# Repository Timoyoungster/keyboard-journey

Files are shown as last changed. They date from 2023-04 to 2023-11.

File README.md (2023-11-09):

# keyboard-journey
*(This repo is for my future self)*
- some crappy plastic full sized keyboard (membrane)
- a sharkoon full sized keyboard (membrane)
- a corsair K70 (mechanical) *not sure about the exact model*
- a razer blackwidow chroma (mechanical; green switches)
- a razer blackwidow chroma (mechanical; orange switches)
- a razer deathstalker pro v2 (mechanical; *i think orange switches*)
- a ferris sweep half-swept (mechanical; Kailh Low Profile Choc Switches Pink (linear / 20gf))

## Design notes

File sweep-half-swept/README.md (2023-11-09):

# Sweep Half Swept

| Front | Back |
| --- | --- |
|  |  |

Half of a Sweep2 with a reversible micro-controller footprint.

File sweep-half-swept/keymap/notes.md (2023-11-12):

# VERY IMPORTANT!!!!
even though it has a TRS/TRRS jack, a TRRS cable is necessary for it to function

If it still doesn't work add the following to the config:
```c
#define SPLIT_USB_DETECT
#define SPLIT_USB_TIMEOUT 2500
```
or try:
```c
#define SPLIT_USB_DETECT
#define SPLIT_USB_TIMEOUT_POLL 10
#define SPLIT_WATCHDOG_ENABLE
#define SPLIT_WATCHDOG_TIMEOUT 3000
```

# KEYMAP SETUP

Make sure to use the LAYOUT_split_3x5 macro for defining the layers (not LAYOUT)

## RULES
SPLIT_KEYBOARD = yes *(to make split mode work)*
COMBO_ENABLE = yes *(to enable the combo feature)*
CONVERT_TO = elite_pi *(to compile for the elite pi controller)*

## CONFIG.H
don't forget to add "#define EE_HANDS" to set the handedness on the EEPROM

# COMPILE & FLASH FIRMWARE
*(board needs to be connected and in boot mode for this
as the command flashes the firmware directly after compilation)*

For the *left side*:
```
qmk flash -bl uf2-split-left
```
For the *right side*:
```
qmk flash -bl uf2-split-right
```

# ELITE-PI - BOOT MODE
In order to get the elite-pi into boot mode it has to be unplugged.

Then the "BOOT" pad and the 4th pin from the top on the right have to be connected with a wire / paperclip or a similar item.

With those two connectors bridged, the USB-C cable has to be plugged in and can only be released when windows recognises the USB-device (when it shows up as a drive in the explorer).

# PROBLEMS
- some weird bug that makes the mouse click unusable when escaping from arrow layer after having selected with shift and arrow keys or something like that; effect is that all mouse clicks deregister right after registering -> nothing can be clicked anymore

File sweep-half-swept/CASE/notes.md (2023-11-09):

# Notes
## Failed Ideas
- screwing a plate onto the bottom piece to hold the PCB from the top doesn’t work because the Elite-PI is on the edge
- using cylindrical extrusions to fit the top to the bottom doesn’t work because the cylinders break easily when a bit of rotational force is applied
- using velcro to attach the PCB to the bottom piece doesn’t work as it makes the PCB feel mushy and if the Elite-PI’s side is pressed down it could damage the cables/ports

## WIP Ideas
### attaching the top to the bottom piece
- DONE: embedding magnets into the top and bottom pieces to keep the surfaces clean and still hold them together tightly (maybe using longer rectangular-shaped ones would be better than circular ones)

### fixating the PCB to the bottom piece
- drill one mounting hole somewhere as far into the middle as possible (inside of the triangle the standoffs form) and use brass insets to fixate the PCB to the case

### making space for the cables
- if possible let the PCB sit higher than the bottom piece’s wall so that there is enough room for the USB-C and AUX cable
- DONE: make a big enough cylindrical "dent"/cutout for the aux port and a similar one in a USB-C shape

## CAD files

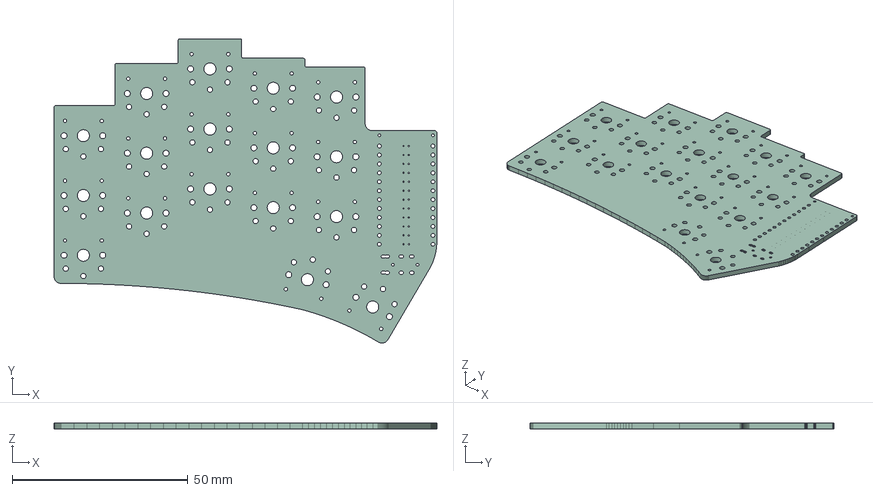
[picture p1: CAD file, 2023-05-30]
sweep-half-swept/half-swept.step
108.9 x 86.5 x 1.58 mm

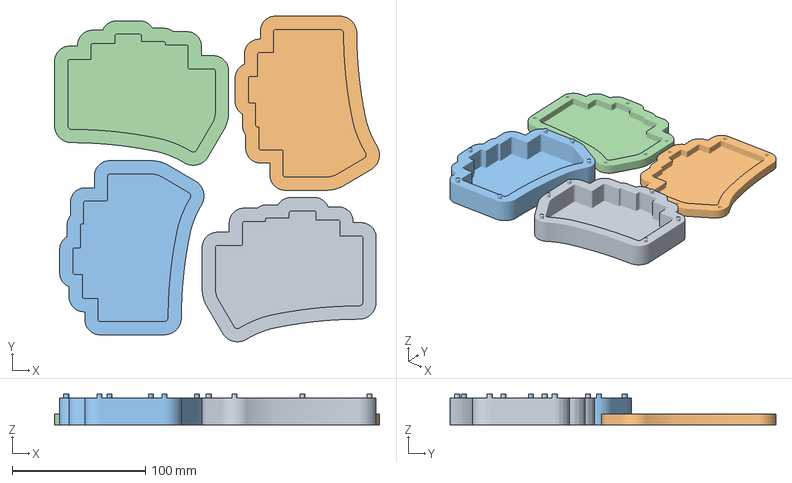
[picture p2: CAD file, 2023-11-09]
sweep-half-swept/CASE/ferris-sweep-case V2.1.3mf
244.3 x 244.8 x 23.0 mm
CASE_top_right
CASE_bottom_right_
CASE_top_left
CASE_bottom_left

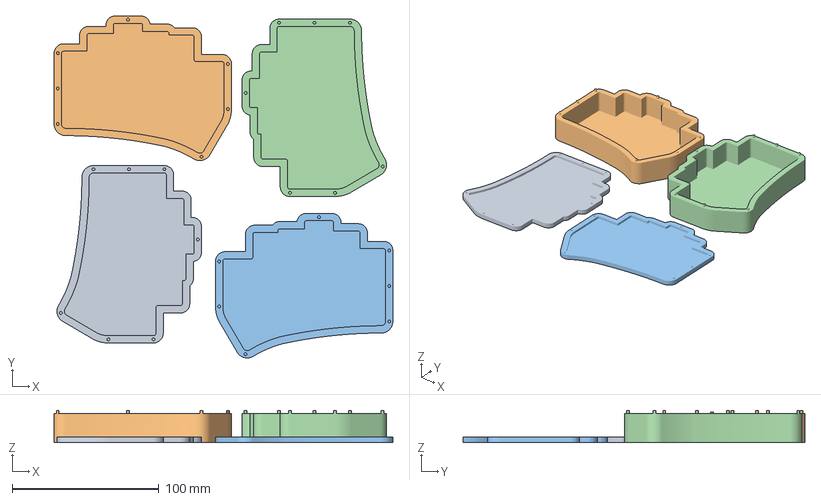
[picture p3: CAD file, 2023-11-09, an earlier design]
sweep-half-swept/CASE/ferris-sweep-case V2.0.3mf
230.9 x 233.0 x 22.0 mm
CASE_Bottom_left
CASE_Bottom_left_(1)
CASE_Bottom_left_(1)_(2)
CASE_Bottom_left_(2)

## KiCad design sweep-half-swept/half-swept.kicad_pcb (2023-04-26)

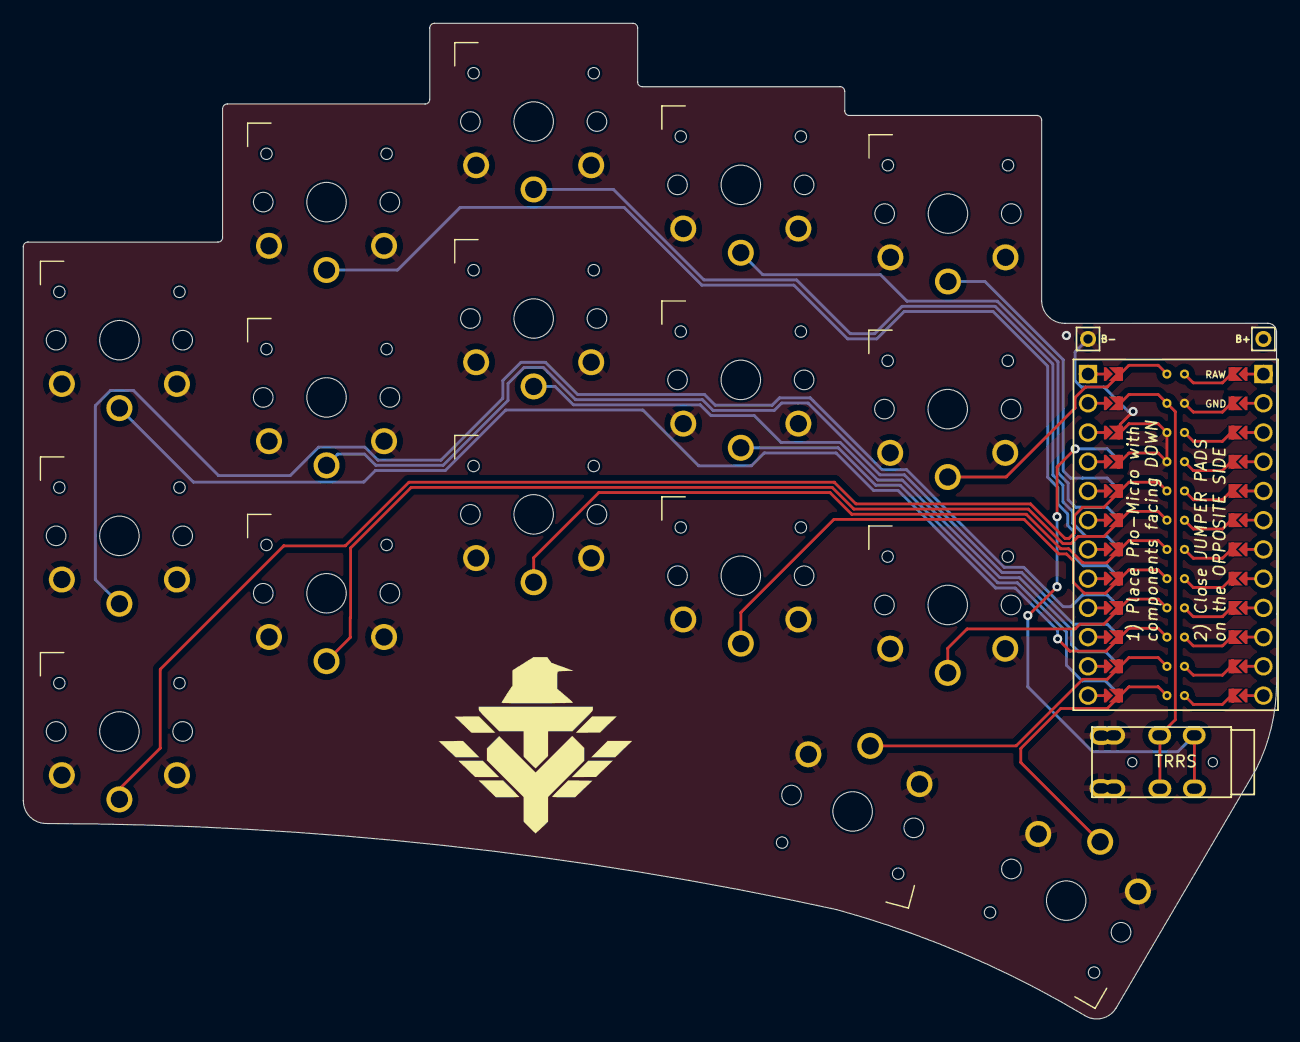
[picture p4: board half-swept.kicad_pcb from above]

Board: 2 copper layers, 108.9 x 86.5 mm, 21 parts (0 on the bottom side), 20 nets.

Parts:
B+: MountingHole_Pad; 1pin_conn
B-: MountingHole_Pad; 1pin_conn
J2: AudioJack4dpb; TRRS-PJ-DPB2
SW1, SW2, SW3, SW4, SW5, SW6, SW7, SW8, SW9, SW10, SW11, SW12, SW13, SW14, SW15, SW16, SW17: SW_Push; SW_PG1350_rev_DPB
U1: ProMicro-kbd; ProMicro_jumpers_facedown

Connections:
Switch1: SW1.1, U1.10
Switch2: SW2.1, U1.17
Switch3: SW3.1, U1.18
Switch4: SW4.1, U1.19
Switch5: SW5.1, U1.20
Switch6: SW6.1, U1.16
Switch7: SW7.1, U1.15
Switch8: SW8.1, U1.14
Switch9: SW9.1, U1.13
Switch10: SW10.1, U1.1
Switch11: SW11.1, U1.5
Switch12: SW12.1, U1.6
Switch13: SW13.1, U1.7
Switch14: SW14.1, U1.8
Switch15: SW15.1, U1.9
Switch16: SW16.1, U1.11
Switch17: SW17.1, U1.12
Switch18: J2.R1, U1.2
gnd: B-.1, J2.S, J2.T, SW1.2, SW2.2, SW3.2, SW4.2, SW5.2, SW6.2, SW7.2, SW8.2, SW9.2, SW10.2, SW11.2, SW12.2, SW13.2, SW14.2, SW15.2, SW16.2, SW17.2, U1.3, U1.4, U1.23
vcc: J2.R2, U1.21

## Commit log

2023-04-19 adding modified pcb files
    [half-swept.kicad_pcb, half-swept.kicad_sch]
2023-04-23 adding keyboard layout ideas
    [half-swept.kicad_pcb, half-swept.kicad_sch]
2023-04-26 adding logo to silkscreen
    [half-swept.kicad_pcb]
2023-04-26 exported gerber file and sent it to production
    [half-swept-B_Cu.gbr, half-swept-B_Mask.gbr, half-swept-B_Paste.gbr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]
2023-04-26 redid the gerber creation with the hole files and resubmitted it to prod
    [half-swept-B_Cu.gbr, half-swept-B_Mask.gbr, half-swept-B_Paste.gbr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]
2023-05-30 exported stepfile
    [half-swept.step]
2023-08-05 switching mouse up/down (+wheel) and arrow up/down to match vim bindings, moving mouse 1 to ring finger
2023-10-30 adding case models and notes
    [ferris-sweep-case V2.0.3mf, ferris-sweep-case V2.1.3mf]
